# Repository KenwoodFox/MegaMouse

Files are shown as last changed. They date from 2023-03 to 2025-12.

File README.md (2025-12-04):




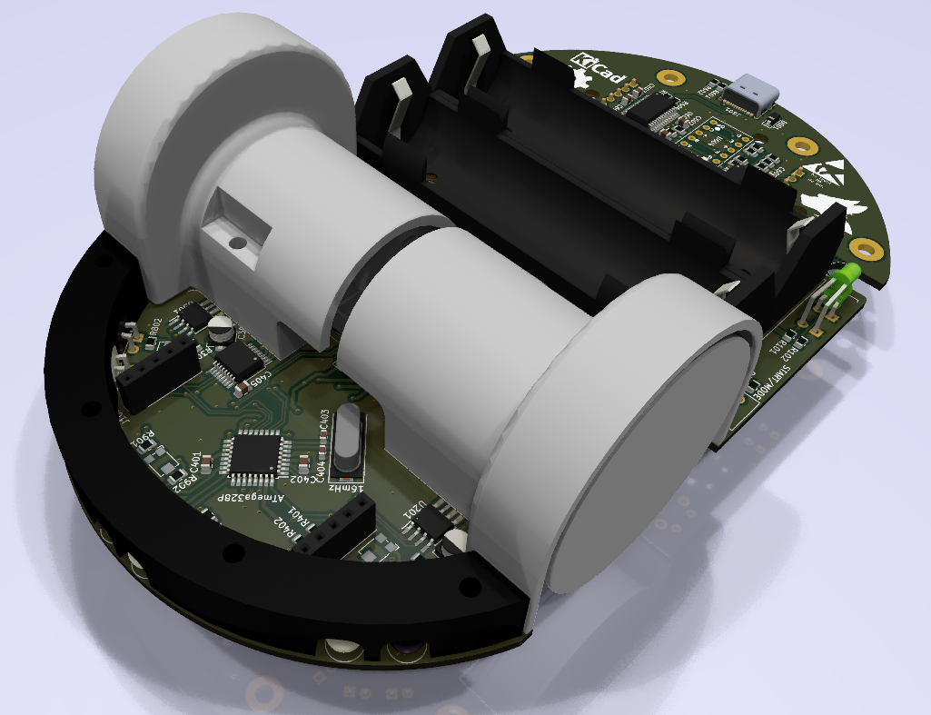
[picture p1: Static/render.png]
Render


# MegaMouse
MegaMouse! An atmega 328p powered micromouse!

# Getting Started

First, begin by cloning this repo and relevant submodules

```shell
git clone --recurse-submodules https://github.com/KenwoodFox/MegaMouse.git
```

Find hardware, software and docs in the directories below!

```
.
├── CAD                   # CAD and 3D models
├── Firmware              # Firmware and on-board code
├── Hardware              # Hardware and design files
│   └── MegaMouse         # PCB Design Files
│       └── Libraries     # KiCAD libraries
└── Static                # Static files
```

# Tag Naming System

```
v1.3
││ │
││ └─ Intermediete revision (reivew, software, minor change)
│└─── Major revision (hardware change, incompatable modification)
└──── Releasable Version
```

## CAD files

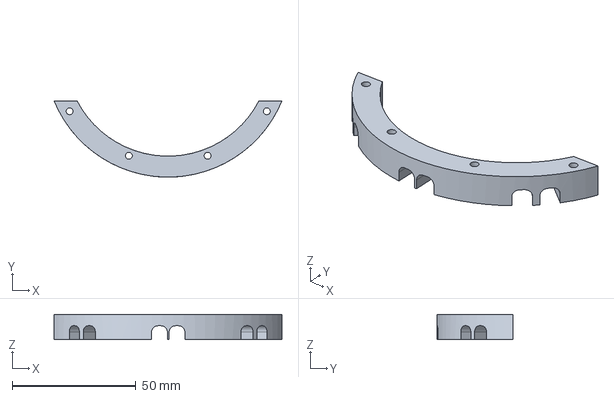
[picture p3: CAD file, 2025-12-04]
CAD/Components/Bridge.FCStd
92.2 x 30.9 x 10.2 mm

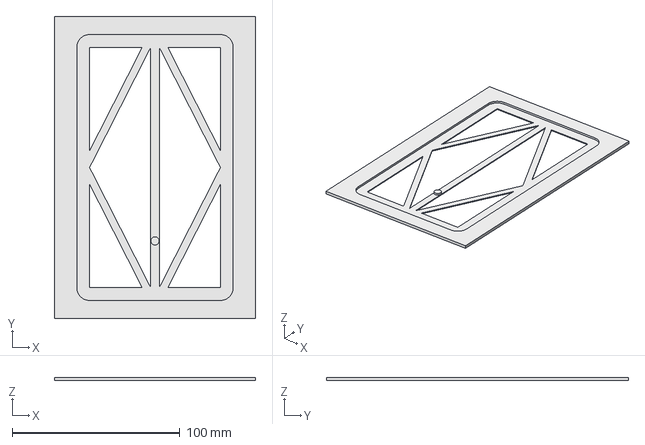
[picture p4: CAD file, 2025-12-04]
CAD/Stencil.FCStd
120.0 x 180.0 x 2.03 mm

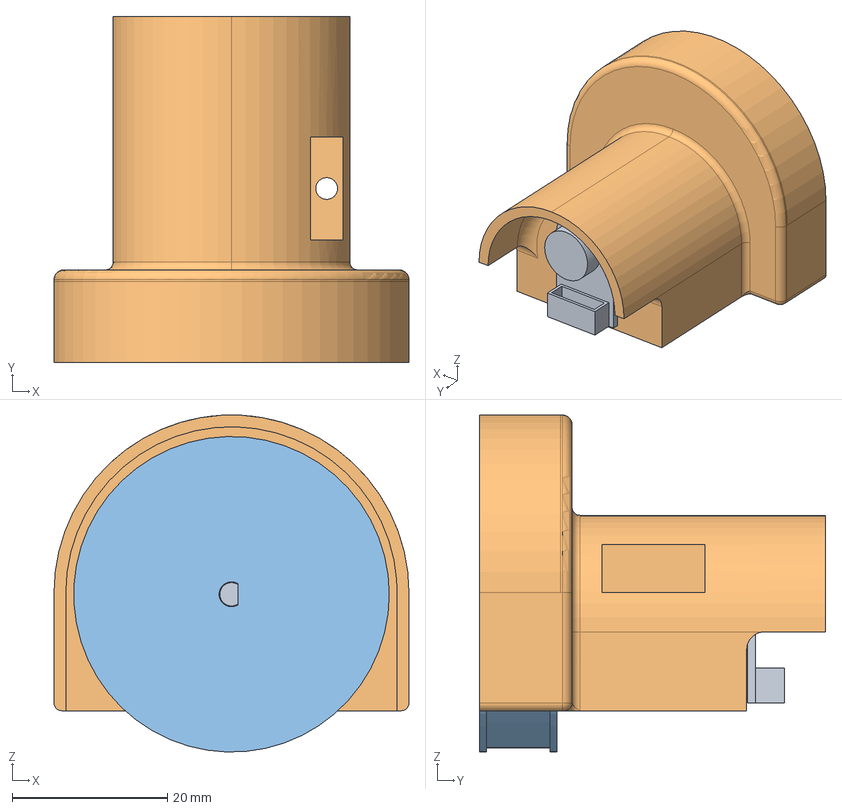
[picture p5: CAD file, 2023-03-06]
CAD/Components/Motor.FCStd
45.7 x 44.6 x 43.4 mm
MotorBody
MotorMount
WheelBody

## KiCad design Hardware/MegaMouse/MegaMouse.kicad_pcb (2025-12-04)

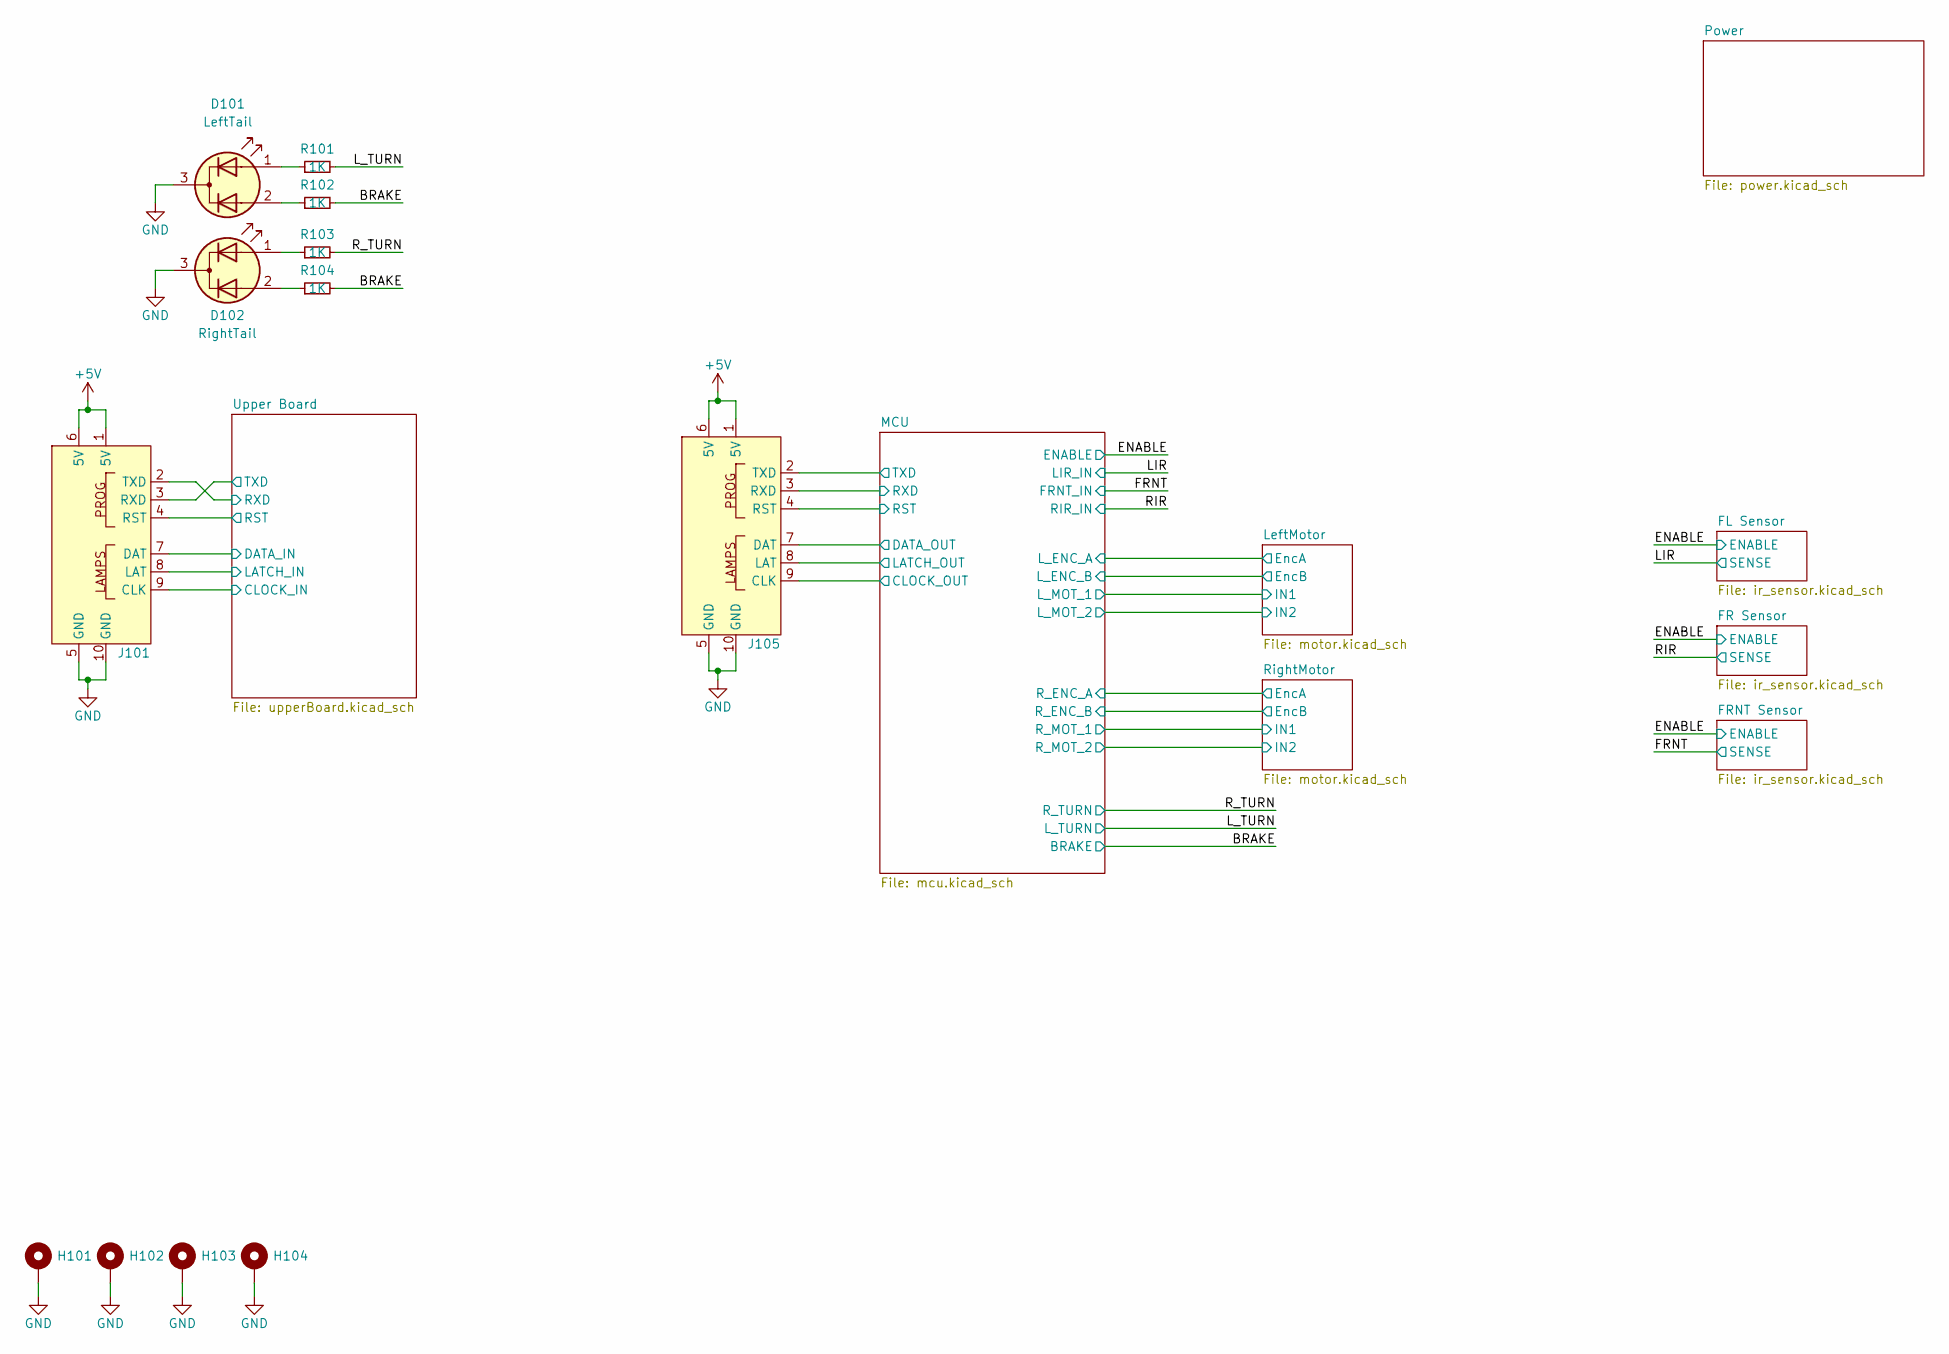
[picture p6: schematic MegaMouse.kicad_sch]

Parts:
D101: LeftTail; BrakeLight
D102: RightTail; BrakeLight
H101, H102, H103, H104: MountingHole_Pad; MountingHole_3mm_Pad
J101, J105: MegaInterconnect
R101, R102, R103, R104: 1K; R_0805_2012Metric

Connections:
+5V: J101.1 (5V), J101.6 (5V), J105.1 (5V), J105.6 (5V); also elsewhere on the board
/BRAKE: R102.2, R104.2; also elsewhere on the board
/L_TURN: R101.2; also elsewhere on the board
/MCU/CLOCK: J105.9 (CLK); also elsewhere on the board
/MCU/DATA_OUT: J105.7 (DAT); also elsewhere on the board
/MCU/LATCH: J105.8 (LAT); also elsewhere on the board
/MCU/RST: J105.4 (RST); also elsewhere on the board
/MCU/RXD: J105.3 (RXD); also elsewhere on the board
/MCU/TXD: J105.2 (TXD); also elsewhere on the board
/R_TURN: R103.2; also elsewhere on the board
/Upper Board/CLOCK_IN: J101.9 (CLK); also elsewhere on the board
/Upper Board/DATA_IN: J101.7 (DAT); also elsewhere on the board
/Upper Board/LATCH_IN: J101.8 (LAT); also elsewhere on the board
/Upper Board/RST: J101.4 (RST); also elsewhere on the board
/Upper Board/RXD: J101.2 (TXD); also elsewhere on the board
/Upper Board/TXD: J101.3 (RXD); also elsewhere on the board
GND: D101.3 (K), D102.3 (K), H101.1, H102.1, H103.1, H104.1, J101.5 (GND), J101.10 (GND), J105.5 (GND), J105.10 (GND); also elsewhere on the board
unnamed: D101.1 (A1), R101.1
unnamed: D101.2 (A2), R102.1
unnamed: D102.1 (A1), R103.1
unnamed: D102.2 (A2), R104.1

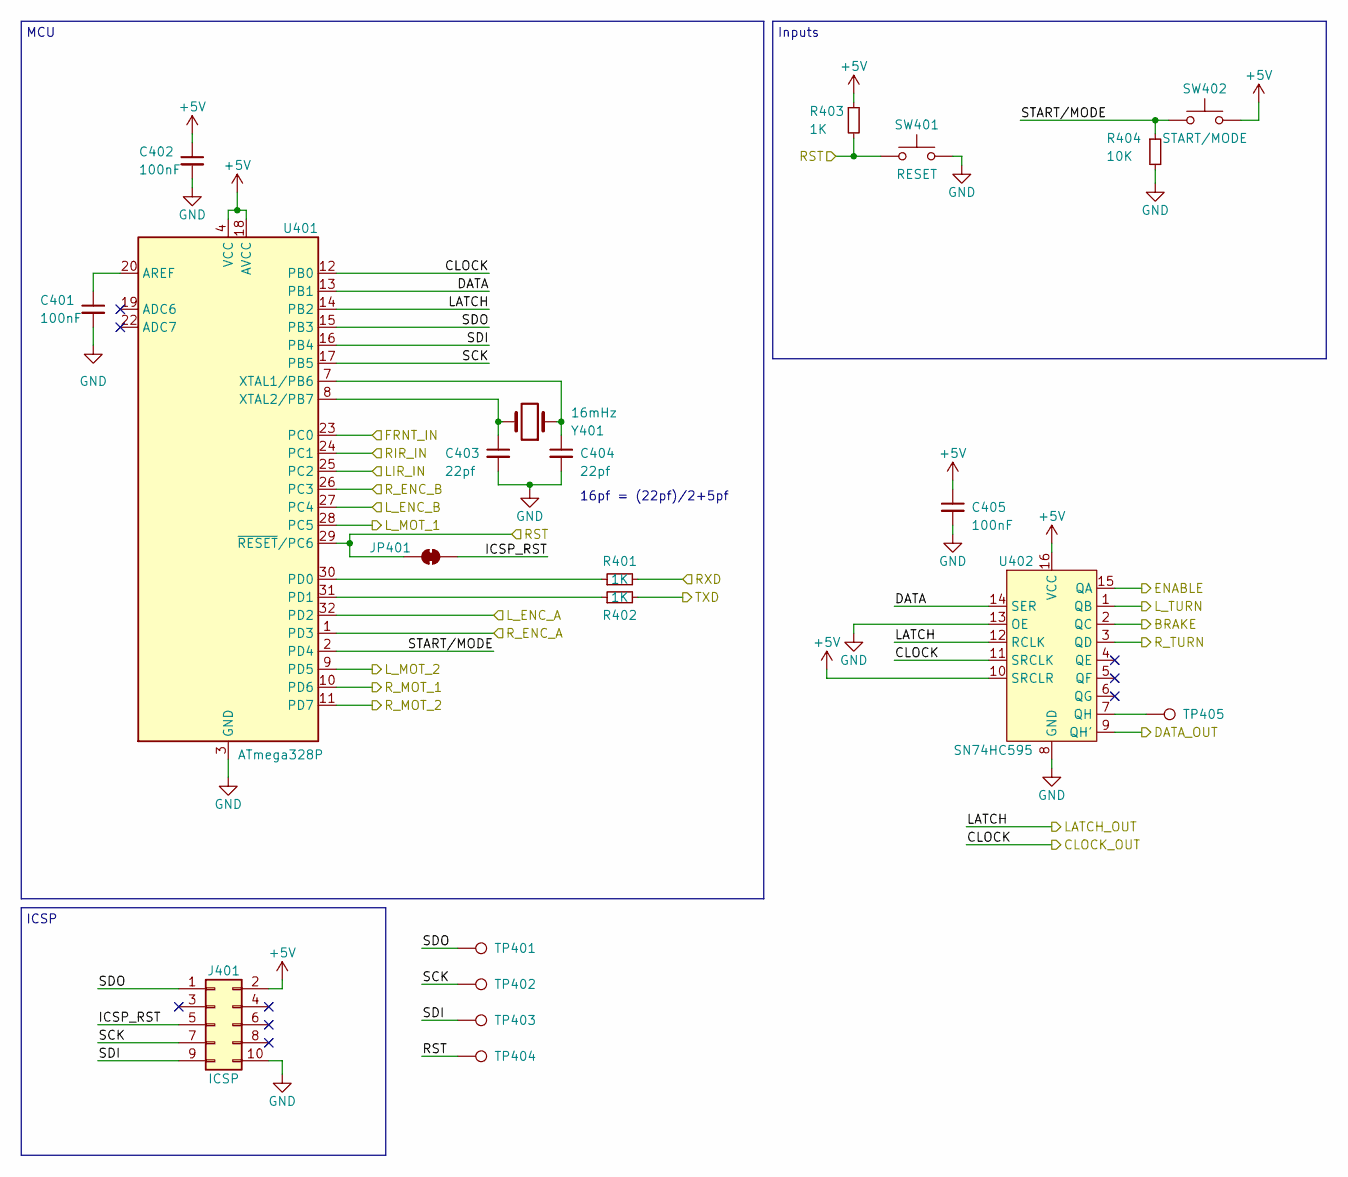
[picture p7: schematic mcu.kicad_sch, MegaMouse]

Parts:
C401, C402, C405: 100nF; C_0805_2012Metric
C403, C404: 22pf; C_0603_1608Metric
J401: ICSP; Tag-Connect_TC2050-IDC-FP_2x05_P1.27mm_Vertical
JP401: RSTBridge; SolderJumper-2_P1.3mm_Bridged_Pad1.0x1.5mm
R401, R402, R403: 1K; R_0805_2012Metric
R404: 10K; R_0805_2012Metric
SW401: RESET; SW_PUSH_6mm_H5mm
SW402: START/MODE; SW_Tactile_SKHH_Angled; LCSC# C384611
TP401, TP402, TP403, TP404, TP405: TestPoint; TestPoint_Pad_2.0x2.0mm
U401: ATmega328P; TQFP-32_7x7mm_P0.8mm
U402: SN74HC595
Y401: 16mHz; Crystal_SMD_HC49-SD

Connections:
+5V: C402.1, C405.1, J401.2, R403.1, SW402.2, U401.4 (VCC), U401.6 (VCC), U401.18 (AVCC), U402.10 (SRCLR), U402.16 (VCC); also elsewhere on the board
/BRAKE: U402.2 (QC); also elsewhere on the board
/ENABLE: U402.15 (QA); also elsewhere on the board
/FRNT: U401.23 (PC0); also elsewhere on the board
/LIR: U401.25 (PC2); also elsewhere on the board
/L_TURN: U402.1 (QB); also elsewhere on the board
/LeftMotor/EncA: U401.32 (PD2); also elsewhere on the board
/LeftMotor/EncB: U401.27 (PC4); also elsewhere on the board
/LeftMotor/IN1: U401.28 (PC5); also elsewhere on the board
/LeftMotor/IN2: U401.9 (PD5); also elsewhere on the board
/MCU/CLOCK: U401.12 (PB0), U402.11 (SRCLK); also elsewhere on the board
/MCU/DATA: U401.13 (PB1), U402.14 (SER)
/MCU/DATA_OUT: U402.9 (QH'); also elsewhere on the board
/MCU/ICSP_RST: J401.5, JP401.2 (B)
/MCU/LATCH: U401.14 (PB2), U402.12 (RCLK); also elsewhere on the board
/MCU/RST: JP401.1 (A), R403.2, SW401.1, TP404.1, U401.29 (~RESET/PC6); also elsewhere on the board
/MCU/RXD: R401.2; also elsewhere on the board
/MCU/R_ENC_A: U401.1 (PD3); also elsewhere on the board
/MCU/R_ENC_B: U401.26 (PC3); also elsewhere on the board
/MCU/R_MOT_1: U401.10 (PD6); also elsewhere on the board
/MCU/R_MOT_2: U401.11 (PD7); also elsewhere on the board
/MCU/SCK: J401.7, TP402.1, U401.17 (PB5)
/MCU/SDI: J401.9, TP403.1, U401.16 (PB4)
/MCU/SDO: J401.1, TP401.1, U401.15 (PB3)
/MCU/START/MODE: R404.1, SW402.1, U401.2 (PD4)
/MCU/TXD: R402.2; also elsewhere on the board
/RIR: U401.24 (PC1); also elsewhere on the board
/R_TURN: U402.3 (QD); also elsewhere on the board
GND: C401.2, C402.2, C403.2, C404.2, C405.2, J401.10, R404.2, SW401.2, U401.3 (GND), U401.5 (GND), U401.21 (GND), U402.8 (GND), U402.13 (OE); also elsewhere on the board
unnamed: C401.1, U401.20 (AREF)
unnamed: R401.1, U401.30 (PD0)
unnamed: R402.1, U401.31 (PD1)
unnamed: C404.1, U401.7 (XTAL1/PB6), Y401.1
unnamed: C403.1, U401.8 (XTAL2/PB7), Y401.2
unnamed: TP405.1, U402.7 (QH)

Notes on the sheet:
ICSP
MCU
Inputs
16pf = (22pf)/2+5pf

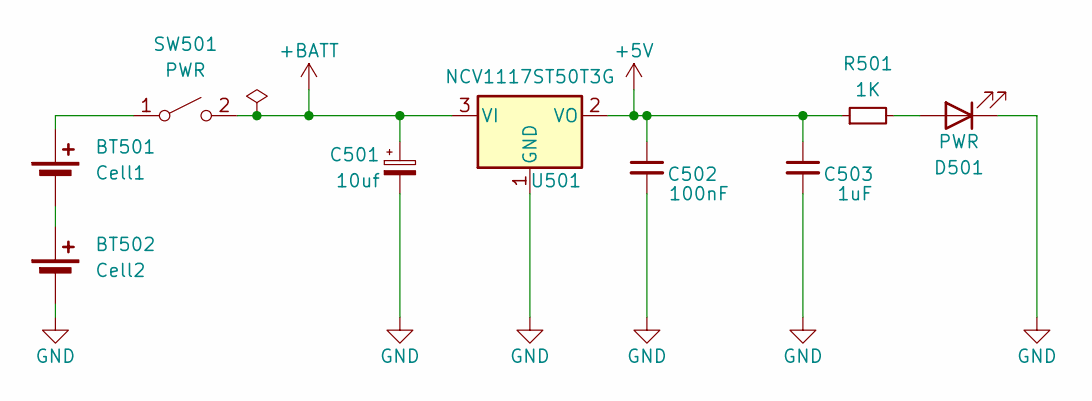
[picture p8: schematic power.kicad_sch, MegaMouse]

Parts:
BT501: Cell1; BatteryHolder_MPD_BH-18650-PC2; LCSC# C5290176
BT502: Cell2; BatteryHolder_MPD_BH-18650-PC2; LCSC# C5290176
C501: 10uf; CP_Elec_4x3
C502: 100nF; C_0805_2012Metric
C503: 1uF; C_0805_2012Metric
D501: PWR; LED_0805_2012Metric
R501: 1K; R_0805_2012Metric
SW501: PWR; EG1218; LCSC# C273394
U501: NCV1117ST50T3G; SOT-223

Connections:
+5V: C502.1, C503.1, R501.1, U501.2 (VO); also elsewhere on the board
+BATT: C501.1, SW501.2 (B), U501.3 (VI); also elsewhere on the board
GND: BT502.2 (-), C501.2, C502.2, C503.2, D501.1 (K), U501.1 (GND); also elsewhere on the board
unnamed: BT501.1 (+), SW501.1 (A)
unnamed: BT501.2 (-), BT502.1 (+)
unnamed: D501.2 (A), R501.2

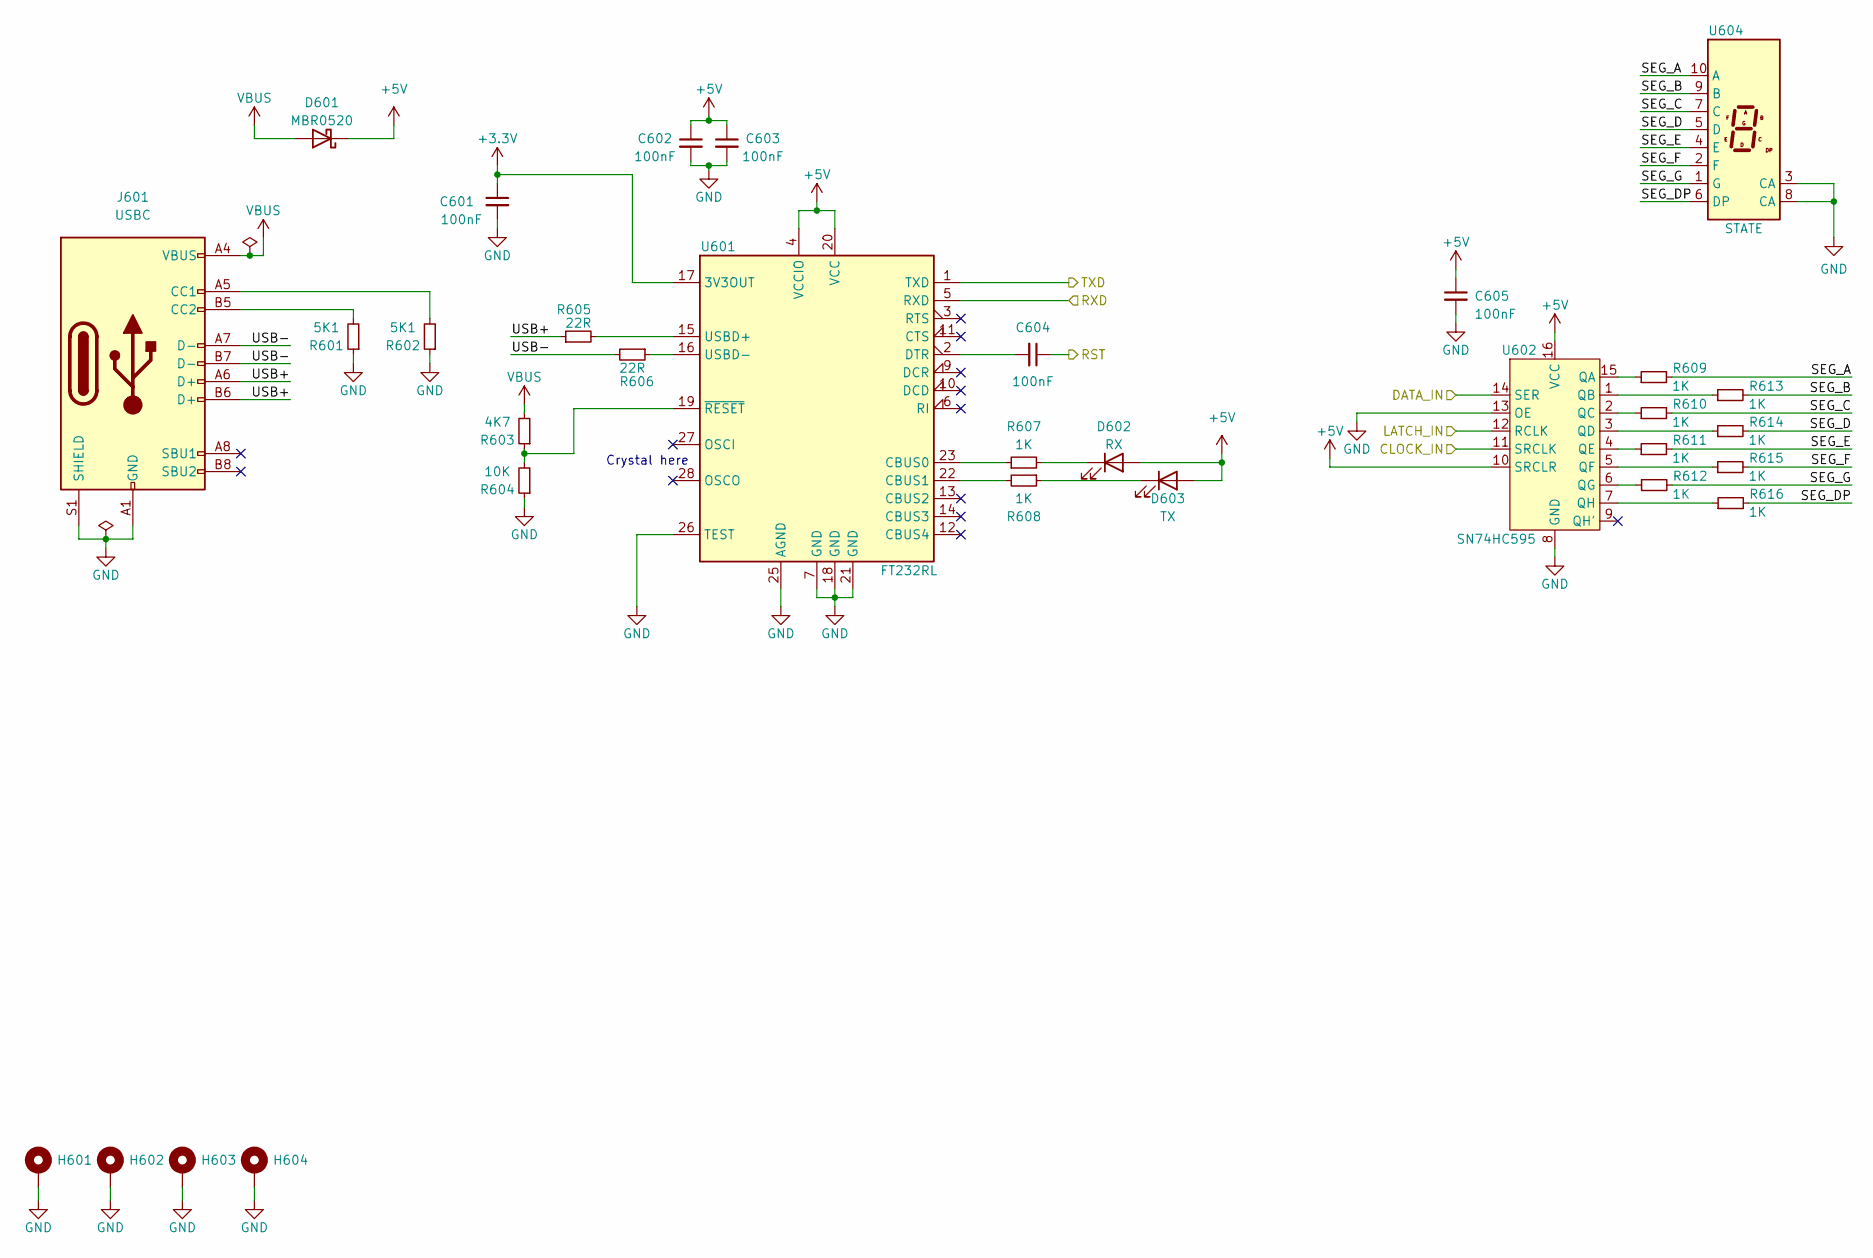
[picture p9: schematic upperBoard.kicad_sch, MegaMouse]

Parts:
C601, C602, C603, C604, C605: 100nF; C_0805_2012Metric
D601: MBR0520; D_SOD-123
D602: RX; LED_0805_2012Metric
D603: TX; LED_0805_2012Metric
H601, H602, H603, H604: MountingHole_Pad; MountingHole_3mm_Pad
J601: USBC; USB_C_Receptacle_XKB_U262-16XN-4BVC11
R601, R602: 5K1; R_0805_2012Metric
R603: 4K7; R_0805_2012Metric
R604: 10K; R_0805_2012Metric
R605, R606: 22R; R_0805_2012Metric
R607, R608, R609, R610, R611, R612, R613, R614, R615, R616: 1K; R_0805_2012Metric
U601: FT232RL; SSOP-28_5.3x10.2mm_P0.65mm; LCSC# C8690
U602: SN74HC595
U604: STATE; SM420391N8

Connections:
+3.3V: C601.1, U601.17 (3V3OUT)
+5V: C602.1, C603.1, C605.1, D601.1 (K), D602.2 (A), D603.2 (A), U601.4 (VCCIO), U601.20 (VCC), U602.10 (SRCLR), U602.16 (VCC); also elsewhere on the board
/Upper Board/CLOCK_IN: U602.11 (SRCLK); also elsewhere on the board
/Upper Board/DATA_IN: U602.14 (SER); also elsewhere on the board
/Upper Board/LATCH_IN: U602.12 (RCLK); also elsewhere on the board
/Upper Board/RST: C604.1; also elsewhere on the board
/Upper Board/RXD: U601.5 (RXD); also elsewhere on the board
/Upper Board/SEG_A: R609.2, U604.10 (A)
/Upper Board/SEG_B: R613.2, U604.9 (B)
/Upper Board/SEG_C: R610.2, U604.7 (C)
/Upper Board/SEG_D: R614.2, U604.5 (D)
/Upper Board/SEG_DP: R616.2, U604.6 (DP)
/Upper Board/SEG_E: R611.2, U604.4 (E)
/Upper Board/SEG_F: R615.2, U604.2 (F)
/Upper Board/SEG_G: R612.2, U604.1 (G)
/Upper Board/TXD: U601.1 (TXD); also elsewhere on the board
/Upper Board/USB+: J601.A6 (D+), J601.B6 (D+), R605.1
/Upper Board/USB-: J601.A7 (D-), J601.B7 (D-), R606.2
GND: C601.2, C602.2, C603.2, C605.2, H601.1, H602.1, H603.1, H604.1, J601.A1 (GND), J601.A12 (GND), J601.B1 (GND), J601.B12 (GND), J601.S1 (SHIELD), R601.1, R602.1, R604.1, U601.7 (GND), U601.18 (GND), U601.21 (GND), U601.25 (AGND), U601.26 (TEST), U602.8 (GND), U602.13 (OE), U604.3 (CA), U604.8 (CA); also elsewhere on the board
unnamed: D602.1 (K), R607.2
unnamed: D603.1 (K), R608.1
unnamed: J601.A5 (CC1), R602.2
unnamed: J601.B5 (CC2), R601.2
unnamed: R607.1, U601.23 (CBUS0)
unnamed: R608.2, U601.22 (CBUS1)
unnamed: C604.2, U601.2 (DTR)
unnamed: R605.2, U601.15 (USBD+)
unnamed: R606.1, U601.16 (USBD-)
unnamed: R603.1, R604.2, U601.19 (~RESET)
unnamed: R609.1, U602.15 (QA)
unnamed: R613.1, U602.1 (QB)
unnamed: R610.1, U602.2 (QC)
unnamed: R614.1, U602.3 (QD)
unnamed: R611.1, U602.4 (QE)
unnamed: R615.1, U602.5 (QF)
unnamed: R612.1, U602.6 (QG)
unnamed: R616.1, U602.7 (QH)
VBUS: D601.2 (A), J601.A4 (VBUS), J601.A9 (VBUS), J601.B4 (VBUS), J601.B9 (VBUS), R603.2

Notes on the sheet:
Crystal here

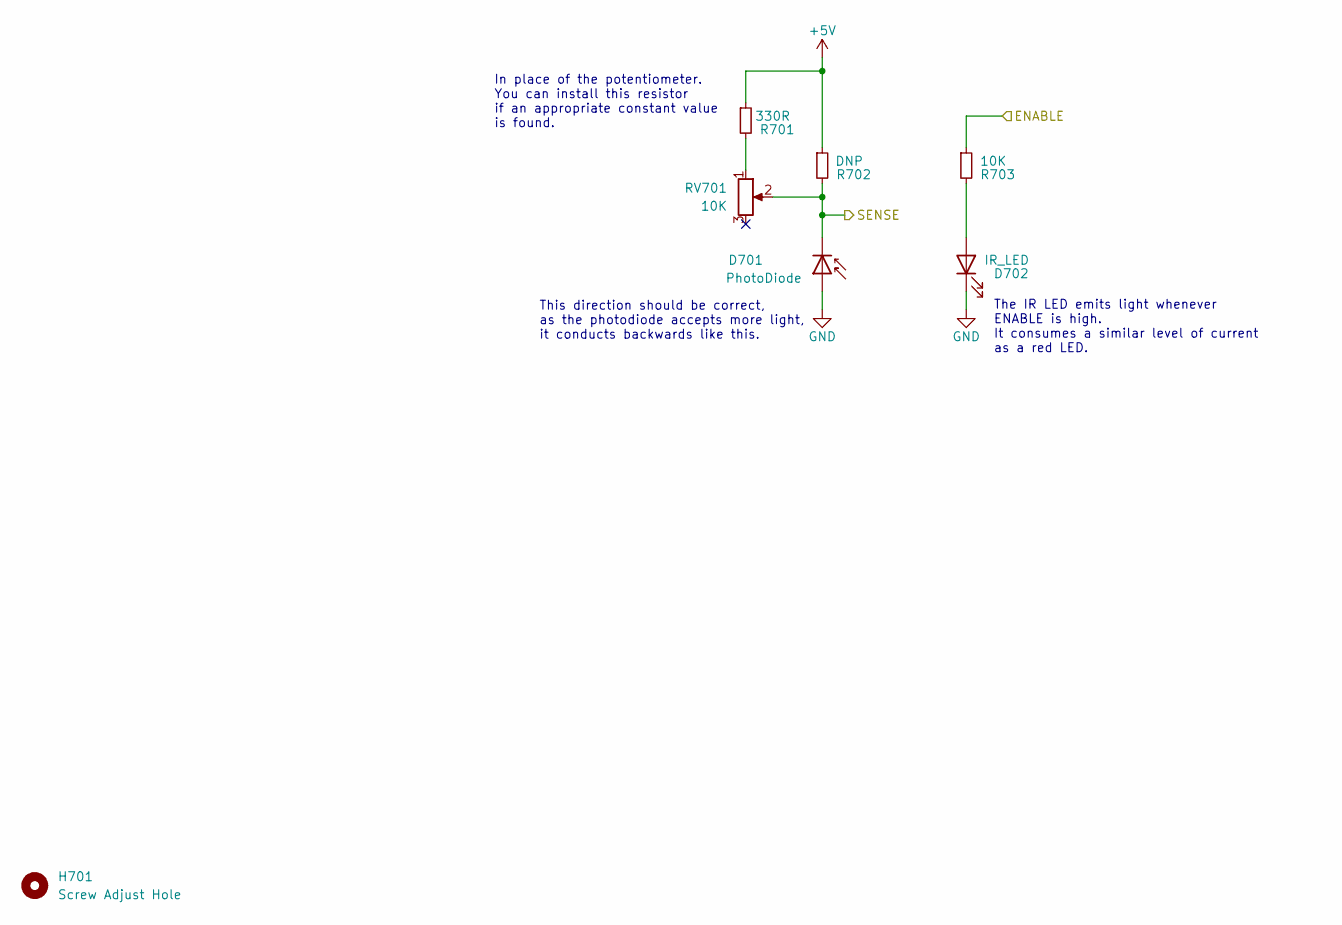
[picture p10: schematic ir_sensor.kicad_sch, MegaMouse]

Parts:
D701: PhotoDiode; LED_D5.0mm_Horizontal_O1.27mm_Z3.0mm_IRBlack
D702: IR_LED; LED_D5.0mm_Horizontal_O1.27mm_Z3.0mm_Clear
H701: Screw Adjust Hole; MountingHole_3mm
R701: 330R; R_0805_2012Metric
R702: DNP; R_0805_2012Metric
R703: 10K; R_0805_2012Metric
RV701: 10K; Potentiometer_Bourns_TC33X_Vertical

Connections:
+5V: R701.1, R702.1; also elsewhere on the board
/ENABLE: R703.1; also elsewhere on the board
/LIR: D701.1 (K), R702.2, RV701.2; also elsewhere on the board
GND: D701.2 (A), D702.1 (K); also elsewhere on the board
unnamed: D702.2 (A), R703.2
unnamed: R701.2, RV701.1

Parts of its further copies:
D801, D901: PhotoDiode; LED_D5.0mm_Horizontal_O1.27mm_Z3.0mm_IRBlack
D802, D902: IR_LED; LED_D5.0mm_Horizontal_O1.27mm_Z3.0mm_Clear
H801, H901: Screw Adjust Hole; MountingHole_3mm
R801, R901: 330R; R_0805_2012Metric
R802, R902: DNP; R_0805_2012Metric
R803, R903: 10K; R_0805_2012Metric
RV801, RV901: 10K; Potentiometer_Bourns_TC33X_Vertical

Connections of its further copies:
+5V: R801.1, R802.1, R901.1, R902.1; also elsewhere on the board
/ENABLE: R803.1, R903.1; also elsewhere on the board
/FRNT: D901.1 (K), R902.2, RV901.2; also elsewhere on the board
/RIR: D801.1 (K), R802.2, RV801.2; also elsewhere on the board
GND: D801.2 (A), D802.1 (K), D901.2 (A), D902.1 (K); also elsewhere on the board
unnamed: D802.2 (A), R803.2
unnamed: D902.2 (A), R903.2
unnamed: R801.2, RV801.1
unnamed: R901.2, RV901.1

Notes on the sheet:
This direction should be correct, as the photodiode accepts more light, it conducts backwards like this.
The IR LED emits light whenever ENABLE is high. It consumes a similar level of current as a red LED.
In place of the potentiometer. You can install this resistor if an appropriate constant value is found.

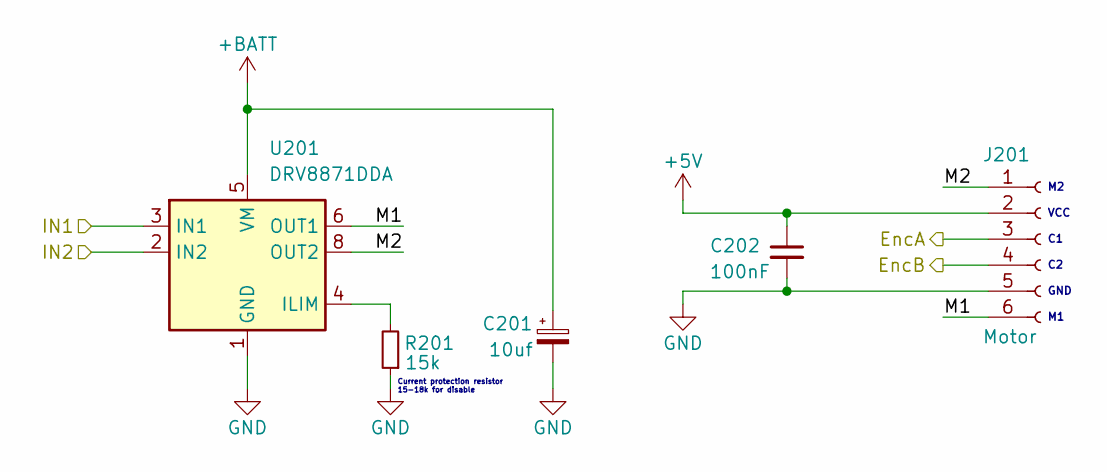
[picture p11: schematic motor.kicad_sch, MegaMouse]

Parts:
C201: 10uf; CP_Elec_4x3
C202: 100nF; C_0805_2012Metric
J201: Motor; MicroMotor
R201: 15k; R_0805_2012Metric
U201: DRV8871DDA; Texas_HTSOP-8-1EP_3.9x4.9mm_P1.27mm_EP2.95x4.9mm_Mask2.4x3.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

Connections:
+5V: C202.1, J201.2; also elsewhere on the board
+BATT: C201.1, U201.5 (VM); also elsewhere on the board
/LeftMotor/EncA: J201.3; also elsewhere on the board
/LeftMotor/EncB: J201.4; also elsewhere on the board
/LeftMotor/IN1: U201.3 (IN1); also elsewhere on the board
/LeftMotor/IN2: U201.2 (IN2); also elsewhere on the board
/LeftMotor/M1: J201.6, U201.6 (OUT1)
/LeftMotor/M2: J201.1, U201.8 (OUT2)
GND: C201.2, C202.2, J201.5, R201.1, U201.1 (GND), U201.7 (GND), U201.9 (GND); also elsewhere on the board
unnamed: R201.2, U201.4 (ILIM)

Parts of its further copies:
C301: 10uf; CP_Elec_4x3
C302: 100nF; C_0805_2012Metric
J301: Motor; MicroMotor
R301: 15k; R_0805_2012Metric
U301: DRV8871DDA; Texas_HTSOP-8-1EP_3.9x4.9mm_P1.27mm_EP2.95x4.9mm_Mask2.4x3.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

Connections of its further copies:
+5V: C302.1, J301.2; also elsewhere on the board
+BATT: C301.1, U301.5 (VM); also elsewhere on the board
/MCU/R_ENC_A: J301.3; also elsewhere on the board
/MCU/R_ENC_B: J301.4; also elsewhere on the board
/MCU/R_MOT_1: U301.3 (IN1); also elsewhere on the board
/MCU/R_MOT_2: U301.2 (IN2); also elsewhere on the board
/RightMotor/M1: J301.6, U301.6 (OUT1)
/RightMotor/M2: J301.1, U301.8 (OUT2)
GND: C301.2, C302.2, J301.5, R301.1, U301.1 (GND), U301.7 (GND), U301.9 (GND); also elsewhere on the board
unnamed: R301.2, U301.4 (ILIM)

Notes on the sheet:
GND
Current protection resistor 15-18k for disable
VCC

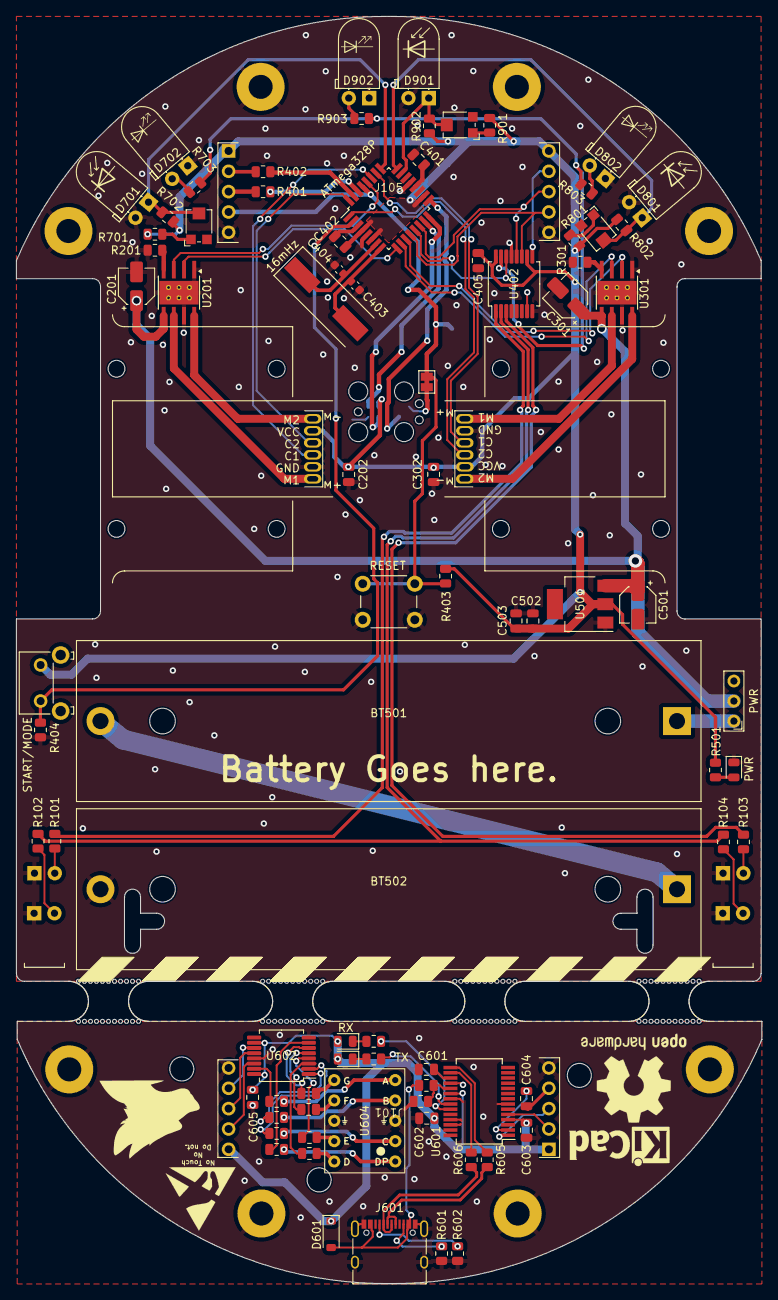
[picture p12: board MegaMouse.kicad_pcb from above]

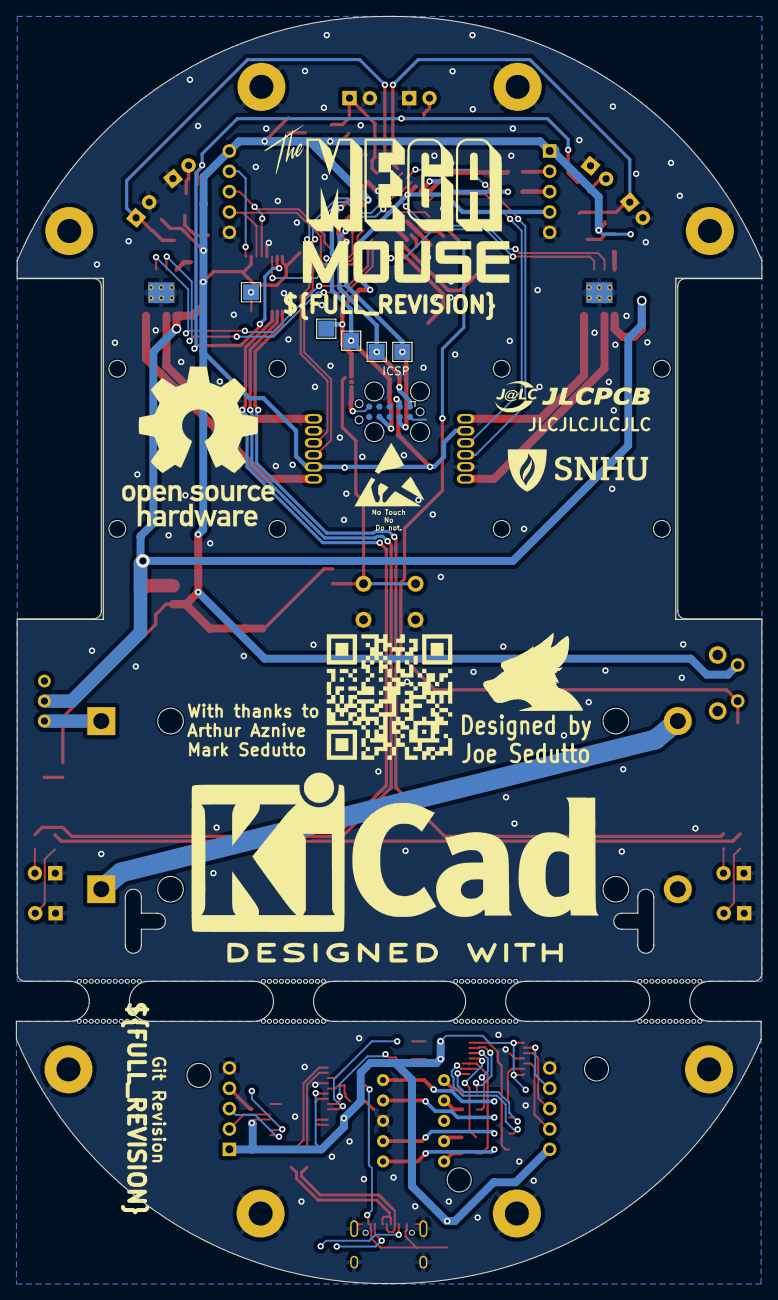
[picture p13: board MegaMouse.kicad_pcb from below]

Board: 2 copper layers, 93.1 x 158.2 mm, 119 parts (7 on the bottom side), 91 nets.

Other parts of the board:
SNHU_NEW***: LOGO; SNHU_NEW
Stripes: Stripes
Stripes#2, Stripes#3, Stripes#4, Stripes#5, Stripes#6, Stripes#7, Stripes#8, Stripes#9: Stripes
mouse-bite-5mm-slot, mouse-bite-5mm-slot#2, mouse-bite-5mm-slot#3, mouse-bite-5mm-slot#4: VAL**; mouse-bite-5mm-slot

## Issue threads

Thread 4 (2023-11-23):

TXD RXD Dont line up on carrier board

KenwoodFox, 2023-11-23:
Discrepancy on debug board, pins dont line up!

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

KenwoodFox, 2023-11-23:
Thank you to @amoskeag for bringing this issue to attention lol

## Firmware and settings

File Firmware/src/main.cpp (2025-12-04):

/**
 * @file main.cpp
 * @author Joe
 * @brief MegaMouse Source Code
 */

// AVR/System
#include <Arduino.h>
// #include <Arduino_FreeRTOS.h>

// Libs
#include "Encoder.h"
#include "algorithm.h"
#include "shiftDisplay.h"

// Pindefs and misc
#include <boardPins.h>

// Objects
Encoder lEnc(LENCA, LENCB);
Algorithm alg;
shiftDisplay num = shiftDisplay(DIN_PIN, CLK_PIN, LAT_PIN);   // Position 0 (furthest from chain)
shiftDisplay lamps = shiftDisplay(DIN_PIN, CLK_PIN, LAT_PIN); // Position 1 (closest)

void setup(void)
{
    // Configure serial
    Serial.begin(115200);
    Serial.println(REV);

    // Ready up fresh algorithm!
    alg.init();

    // Initalize displays and lights
    num.begin();
    lamps.begin();

    // Pins
    pinMode(LMOT1, OUTPUT);
    pinMode(LMOT2, OUTPUT);

    pinMode(CLK_PIN, OUTPUT);
}

long oldPosition = -999;
uint8_t _t = 0;

void loop()
{
    long newPosition = lEnc.read();
    if (newPosition != oldPosition)
    {
        oldPosition = newPosition;
        Serial.println(newPosition);
    }

    analogWrite(LMOT1, 120);
    analogWrite(LMOT2, 0);

    num.setDecimal(millis() % 1000 > 500);
    // num.setDigit(_t);

    // 0b00001000 Right turn signal
    // 0b00000100 Brakes
    // 0b00000010 Left

    if ((millis() / 1000) % 2 == 0)
    {
        lamps.setRaw(0b00001000 | 0b00000010);
    }
    else
    {
        lamps.setRaw(0);
    }

    delay(100);

    _t++;
    if (_t > 10)
    {
        _t = 0;
    }

    Serial.println(_t);
}

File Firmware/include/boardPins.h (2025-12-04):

#include <Arduino.h>

#ifndef _BOARD_PINS_H
#define _BOARD_PINS_H

// Encoders
#define LENCA 2  // PD2
#define LENCB A4 // PC4
#define RENCA 3  // PD3
#define RENCB A3 // PC3

// Motors
#define LMOT1 A5 // PC5
#define LMOT2 5  // PD5

// Shift Pins
#define DIN_PIN 9
#define CLK_PIN 8
#define LAT_PIN 10

#endif

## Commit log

2023-03-01 Create 3d model for motors
    [MegaMouse.kicad_pcb, MegaMouse.kicad_sch, Motor-MotorBody.step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]
2023-03-01 Brake lights!
    [MegaMouse.kicad_pcb, MegaMouse.kicad_sch, Wheel.FCStd]
2023-03-02 Bump libs
    [MegaMouse.kicad_pcb]
2023-03-02 Add brakelight as full kicad_mod
    [MegaMouse.kicad_pcb, MegaMouse.kicad_sch]
2023-03-03 Make awesome
    [MegaMouse.kicad_pcb, MegaMouse.kicad_sch, Motor.FCStd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]
2023-03-06 Clean board
    [MegaMouse.kicad_pcb, MegaMouse.kicad_sch, Motor.FCStd]
2023-03-20 Add second layer
    [MegaMouse.kicad_pcb, MegaMouse.kicad_sch, mcu.kicad_sch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]
2023-03-20 Add panelization
    [MegaMouse.kicad_pcb]
2023-03-20 move upper body
    [MegaMouse.kicad_pcb, MegaMouse.kicad_sch, upperBoard.kicad_sch]
2023-03-23 Throw on second layer and target a v1.0
    [MegaMouse.kicad_pcb, MegaMouse.kicad_sch, power.kicad_sch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]
2023-03-24 Bump all
    [MegaMouse.kicad_pcb]
2023-03-24 Even more stuff! also bump libs
    [MegaMouse.kicad_pcb, MegaMouse.kicad_sch, mcu.kicad_sch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]
2023-03-25 Remove inaccesable datasheet
    [upperBoard.kicad_sch]
2023-03-25 Bump config
    [MegaMouse.kicad_sch, mcu.kicad_sch, motor.kicad_sch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]
2023-03-27 There should be no mention of any datasheet for that diodeg
    [MegaMouse.kicad_pcb, MegaMouse.kicad_sch, upperBoard.kicad_sch]
2023-03-27 remove verbose
    [mcu.kicad_sch]
2023-03-27 Add silk
    [MegaMouse.kicad_pcb]
2023-03-27 Add decoupling caps and 3d models
    [MegaMouse.kicad_pcb, MegaMouse.kicad_sch, mcu.kicad_sch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]
2023-03-27 Fix crystal
    [MegaMouse.kicad_pcb, MegaMouse.kicad_sch, mcu.kicad_sch]
2023-03-27 Add more wiring
    [MegaMouse.kicad_pcb, MegaMouse.kicad_sch, mcu.kicad_sch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]
2023-03-28 Add IR sensor
    [MegaMouse.kicad_pcb, MegaMouse.kicad_sch, ir_sensor.kicad_sch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]
2023-03-28 Add silkscreen!
    [MegaMouse.kicad_pcb, MegaMouse.kicad_sch, mcu.kicad_sch]
2023-03-28 Add inital photodiodes
    [MegaMouse.kicad_pcb, MegaMouse.kicad_sch, ir_sensor.kicad_sch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]
2023-03-28 Add in some more, random junk
    [MegaMouse.kicad_pcb, MegaMouse.kicad_sch, ir_sensor.kicad_sch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]
2023-03-29 Add lines for enabling emittersg
    [MegaMouse.kicad_pcb, mcu.kicad_sch]
2023-03-29 Remove LCSC to fix builds
    [ir_sensor.kicad_sch]
2023-03-29 Fix DRC and prep for a v1.0 release!
    [MegaMouse.kicad_pcb]
2023-03-30 Carlstrom Review (#2)
    Thank you to Professor Carlstrom for reviewing!
    [MegaMouse.kicad_pcb, MegaMouse.kicad_sch, ir_sensor.kicad_sch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]
2025-12-04 Verification 1 (#3)
    And thats all we have time for folks.
    [Bridge.FCStd, MegaMouse.kicad_pcb, MegaMouse.kicad_sch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]
